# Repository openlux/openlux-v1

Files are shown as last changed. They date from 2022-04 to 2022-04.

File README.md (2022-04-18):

This is the first version of this camera and had a few small design issues, these will be fixed in v2.

# openlux

openlux is an open source design for an astrophotography camera designed around the KAI-11002 CCD sensor.

### Hardware specifications

* 4-layer PCB

* KAI-11002 CCD sensor
  * 4008x2672 resolution
  * 43.3mm diagonal size
  * 9um pixels
  * Interline transfer
  * Electronic shutter

* AD9826 ADC
  * Correlated double sampling
  * 16-bit

* ATmega328P + FT2232H
  * High speed USB 2.0 (480Mb/s)

### Sample photo

* 32x 5min lights (2hrs 40mins total), 16x darks, 16x flats, 16x dark flats
* AT65EDQ + HEQ5
* ST80 & ASI174MM for guiding

M31 sample photo

### PCB render

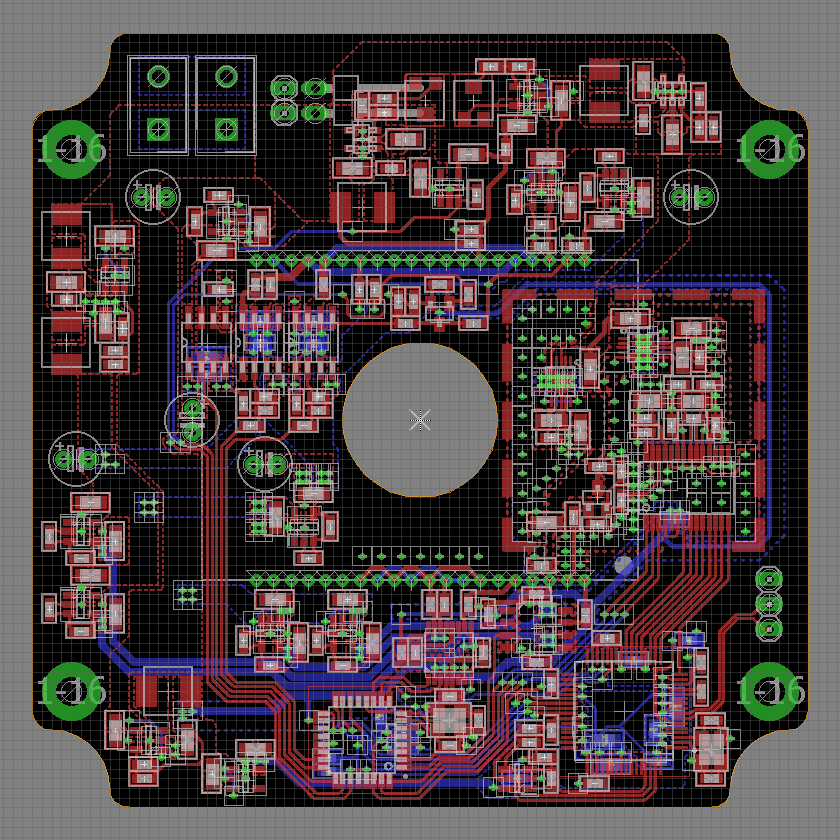
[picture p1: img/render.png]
PCB render


### Photos

PCB photo

Camera photo

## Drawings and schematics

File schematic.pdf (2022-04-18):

A

A

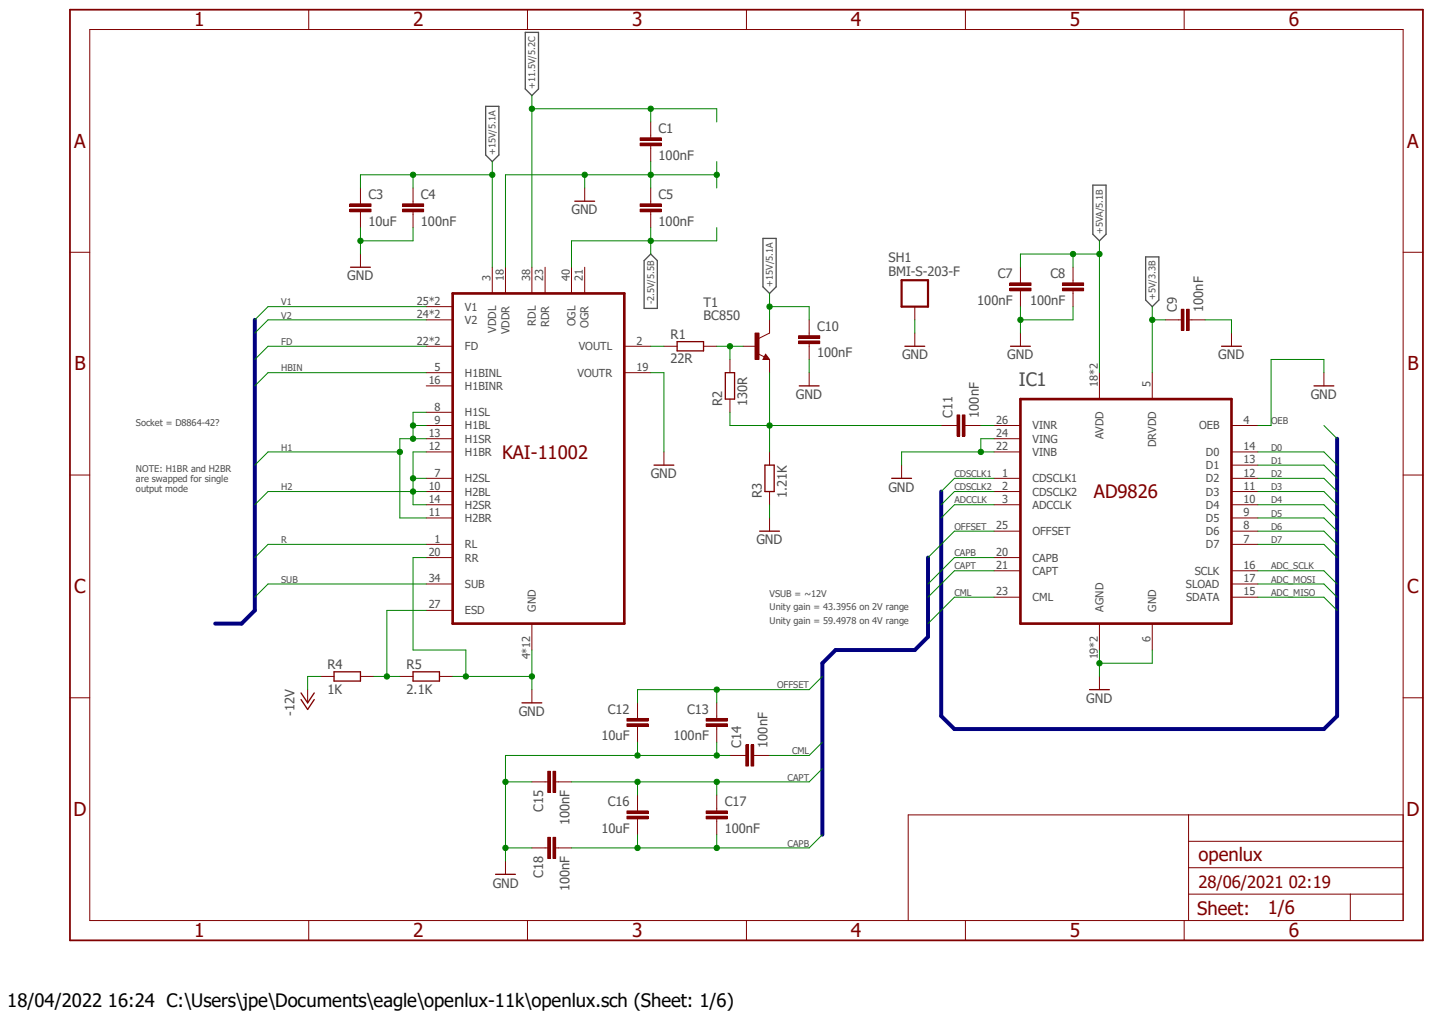
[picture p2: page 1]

NOTE: H1BR and H2BR
are swapped for single
output mode

VSUB = ~12V
Unity gain = 43.3956 on 2V range
Unity gain = 59.4978 on 4V range

18/04/2022 16:24 C:\Users\jpe\Documents\eagle\openlux-11k\openlux.sch (Sheet: 1/6)

A

A

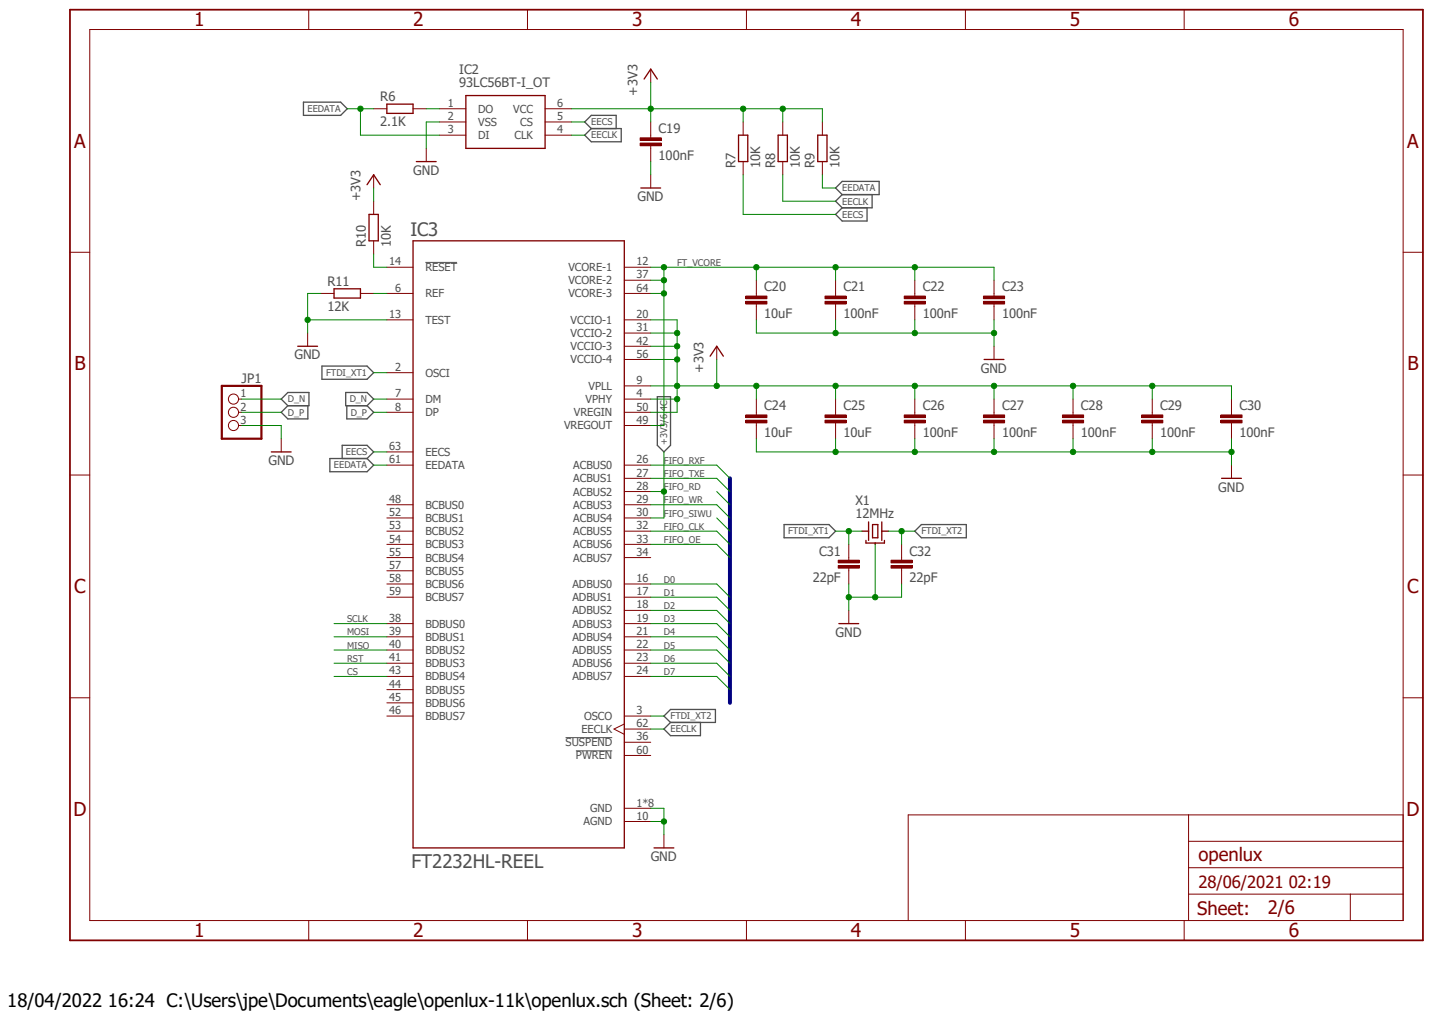
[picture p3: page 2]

18/04/2022 16:24 C:\Users\jpe\Documents\eagle\openlux-11k\openlux.sch (Sheet: 2/6)

## wr IC4

A

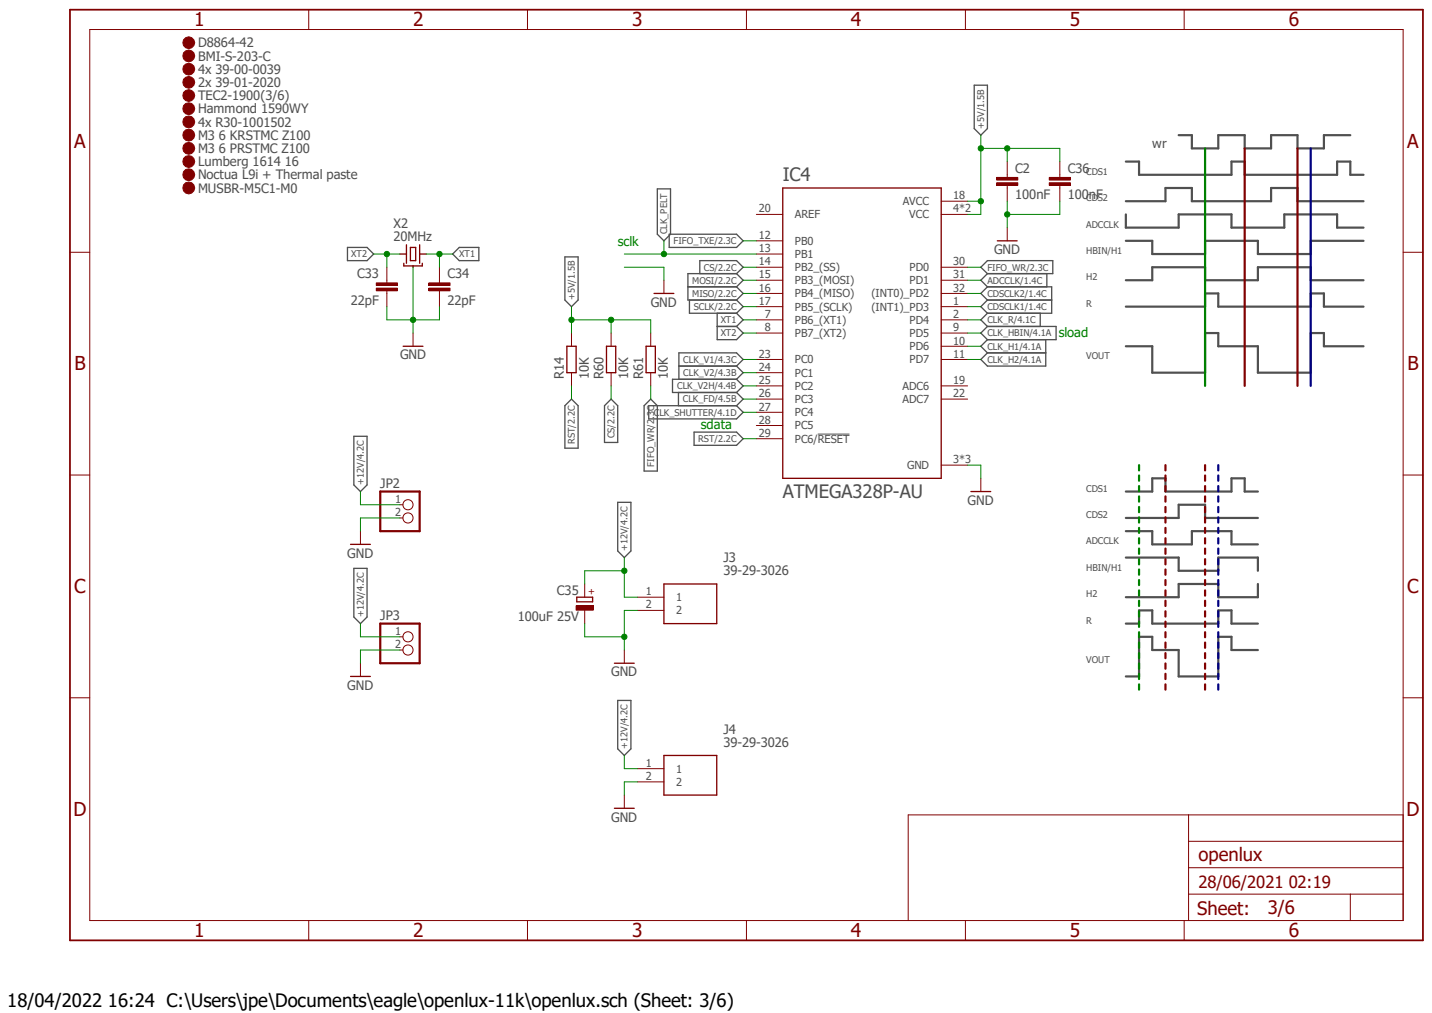
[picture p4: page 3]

18/04/2022 16:24 C:\Users\jpe\Documents\eagle\openlux-11k\openlux.sch (Sheet: 3/6)

A

A

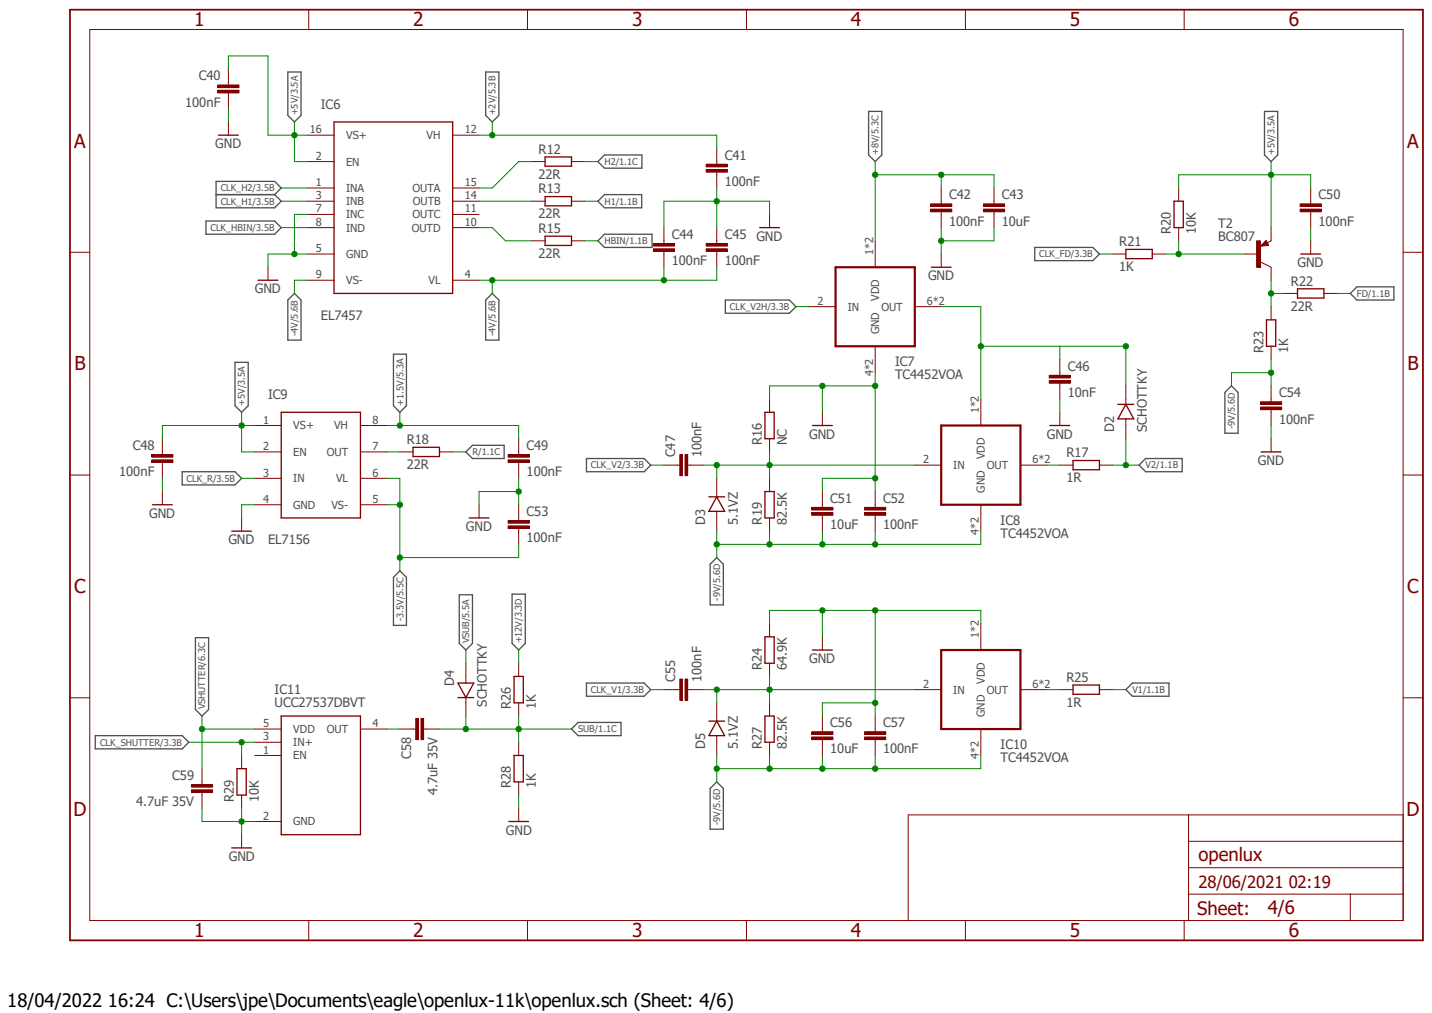
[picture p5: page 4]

18/04/2022 16:24 C:\Users\jpe\Documents\eagle\openlux-11k\openlux.sch (Sheet: 4/6)

OUT | 5 R³¹ R³⁵
C63 | R⁴¹

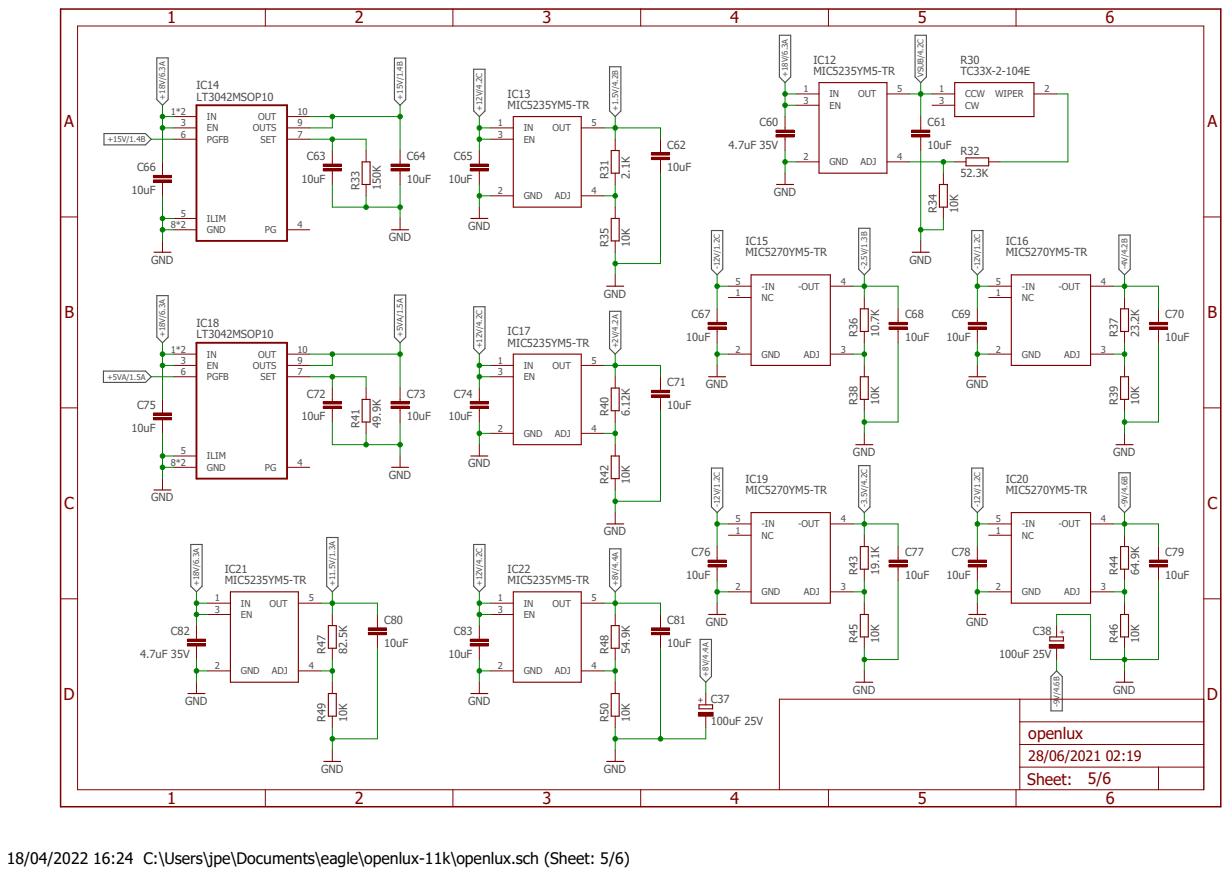
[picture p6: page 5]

18/04/2022 16:24 C:\Users\jpe\Documents\eagle\openlux-11k\openlux.sch (Sheet: 5/6)

A

A

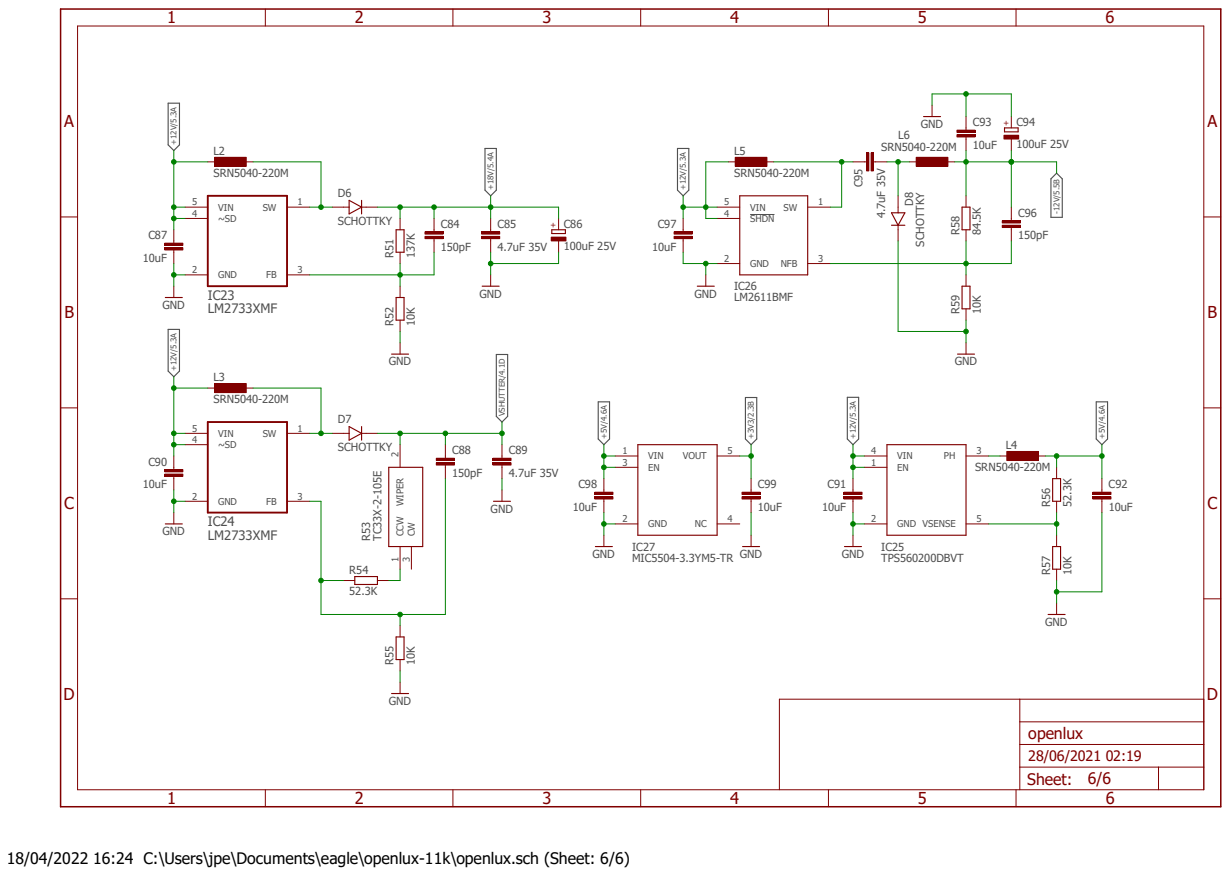
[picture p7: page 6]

18/04/2022 16:24 C:\Users\jpe\Documents\eagle\openlux-11k\openlux.sch (Sheet: 6/6)

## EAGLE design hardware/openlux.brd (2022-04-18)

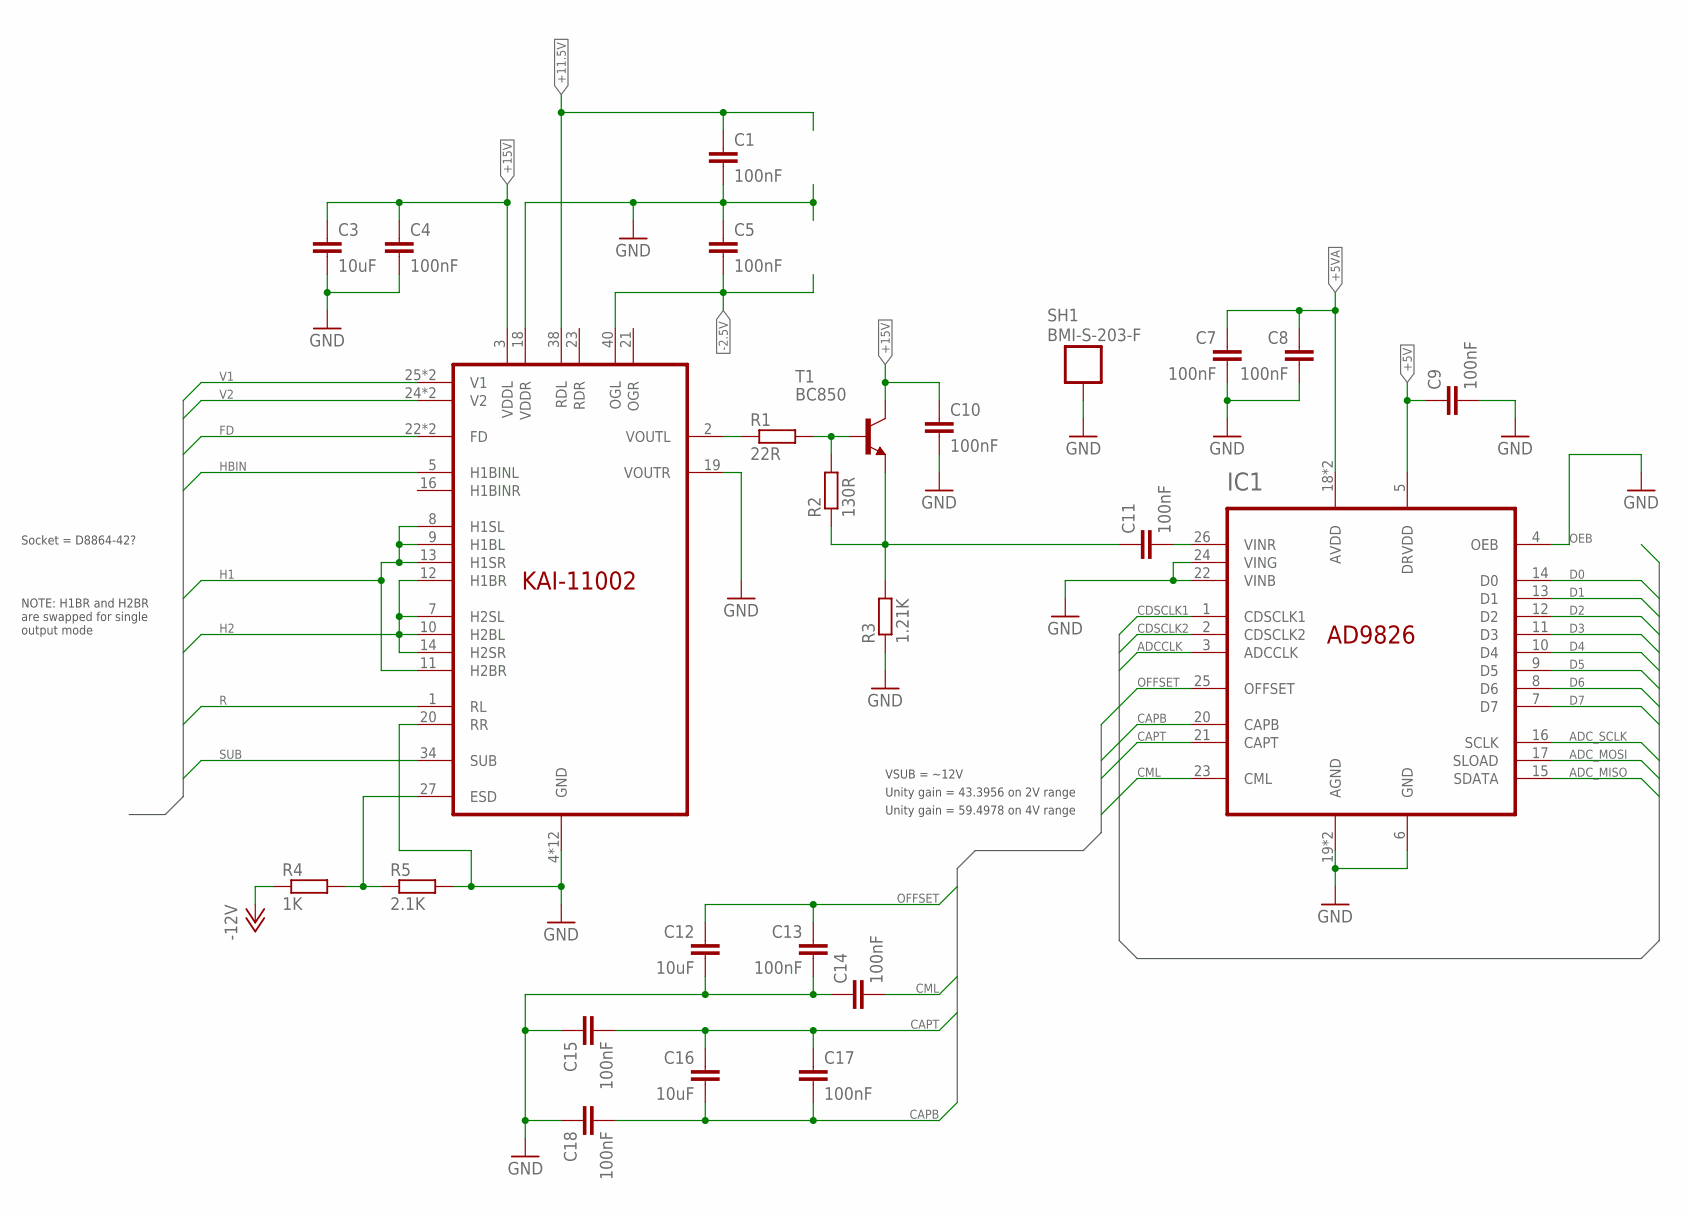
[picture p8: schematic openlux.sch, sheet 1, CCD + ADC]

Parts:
C1, C4, C5, C7, C8, C9, C10, C11, C13, C14, C15, C17, C18: 100nF; 0603
C3, C12, C16: 10uF; 0805
IC1: AD9826; SSOP28
IS1: KAI-11002
R1: 22R; 0603
R2: 130R; 0603
R3: 1.21K; 0603
R4: 1K; 0603
R5: 2.1K; 0603
SH1: BMI-S-203-F
T1: BC850; SOT23

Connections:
+5V: C9.1, IC1.5 (DRVDD); also elsewhere on the board
+5VA: C7.1, C8.1, IC1.18 (AVDD), IC1.28 (AVDD); also elsewhere on the board
+11.5V: C1.1, IS1.38 (RDL); also elsewhere on the board
+15V: C3.1, C4.1, C10.1, IS1.3 (VDDL), T1.3 (C); also elsewhere on the board
-2.5V: C5.2, IS1.40 (OGL); also elsewhere on the board
-12V: R4.1; also elsewhere on the board
ADCCLK: IC1.3 (ADCCLK); also elsewhere on the board
ADC_MISO: IC1.15 (SDATA)
ADC_MOSI: IC1.17 (SLOAD)
ADC_SCLK: IC1.16 (SCLK)
CAPB: C16.2, C17.2, C18.2, IC1.20 (CAPB)
CAPT: C15.2, C16.1, C17.1, IC1.21 (CAPT)
CDSCLK1: IC1.1 (CDSCLK1); also elsewhere on the board
CDSCLK2: IC1.2 (CDSCLK2); also elsewhere on the board
CML: C14.2, IC1.23 (CML)
D0: IC1.14 (D0); also elsewhere on the board
D1: IC1.13 (D1); also elsewhere on the board
D2: IC1.12 (D2); also elsewhere on the board
D3: IC1.11 (D3); also elsewhere on the board
D4: IC1.10 (D4); also elsewhere on the board
D5: IC1.9 (D5); also elsewhere on the board
D6: IC1.8 (D6); also elsewhere on the board
D7: IC1.7 (D7); also elsewhere on the board
FD: IS1.22 (FD), IS1.39 (FD); also elsewhere on the board
GND: C1.2, C3.2, C4.2, C5.1, C7.2, C8.2, C9.2, C10.2, C12.2, C13.2, C14.1, C15.1, C18.1, IC1.4 (OEB), IC1.6 (GND), IC1.19 (AGND), IC1.22 (VINB), IC1.24 (VING), IC1.27 (AGND), IS1.4 (GND), IS1.6 (GND), IS1.15 (GND), IS1.17 (GND), IS1.18 (VDDR), IS1.19 (VOUTR), IS1.20 (RR), IS1.26 (GND), IS1.28 (GND), IS1.29 (GND), IS1.30 (GND), IS1.31 (GND), IS1.32 (GND), IS1.33 (GND), IS1.35 (GND), R3.1, R5.2, SH1.P$1, SH1.P$2, SH1.P$3, SH1.P$4, SH1.P$5, SH1.P$6, SH1.P$7, SH1.P$8, SH1.P$9, SH1.P$10, SH1.P$11, SH1.P$12, SH1.P$13, SH1.P$14, SH1.P$15, SH1.P$19, SH1.P$20; also elsewhere on the board
H1: IS1.8 (H1SL), IS1.9 (H1BL), IS1.11 (H2BR), IS1.13 (H1SR); also elsewhere on the board
H2: IS1.7 (H2SL), IS1.10 (H2BL), IS1.12 (H1BR), IS1.14 (H2SR); also elsewhere on the board
HBIN: IS1.5 (H1BINL); also elsewhere on the board
unnamed: R1.2, R2.2, T1.1 (B)
unnamed: C11.2, IC1.26 (VINR)
unnamed: IS1.2 (VOUTL), R1.1
OFFSET: C12.1, C13.1, IC1.25 (OFFSET)
R: IS1.1 (RL); also elsewhere on the board
SUB: IS1.34 (SUB); also elsewhere on the board
V1: IS1.25 (V1), IS1.37 (V1); also elsewhere on the board
V2: IS1.24 (V2), IS1.36 (V2); also elsewhere on the board
VESD: IS1.27 (ESD), R4.2, R5.1
VOUT: C11.1, R2.1, R3.2, T1.2 (E)

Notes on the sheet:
NOTE: H1BR and H2BR are swapped for single output mode
Unity gain = 43.3956 on 2V range
Unity gain = 59.4978 on 4V range
Socket = D8864-42?
VSUB = ~12V

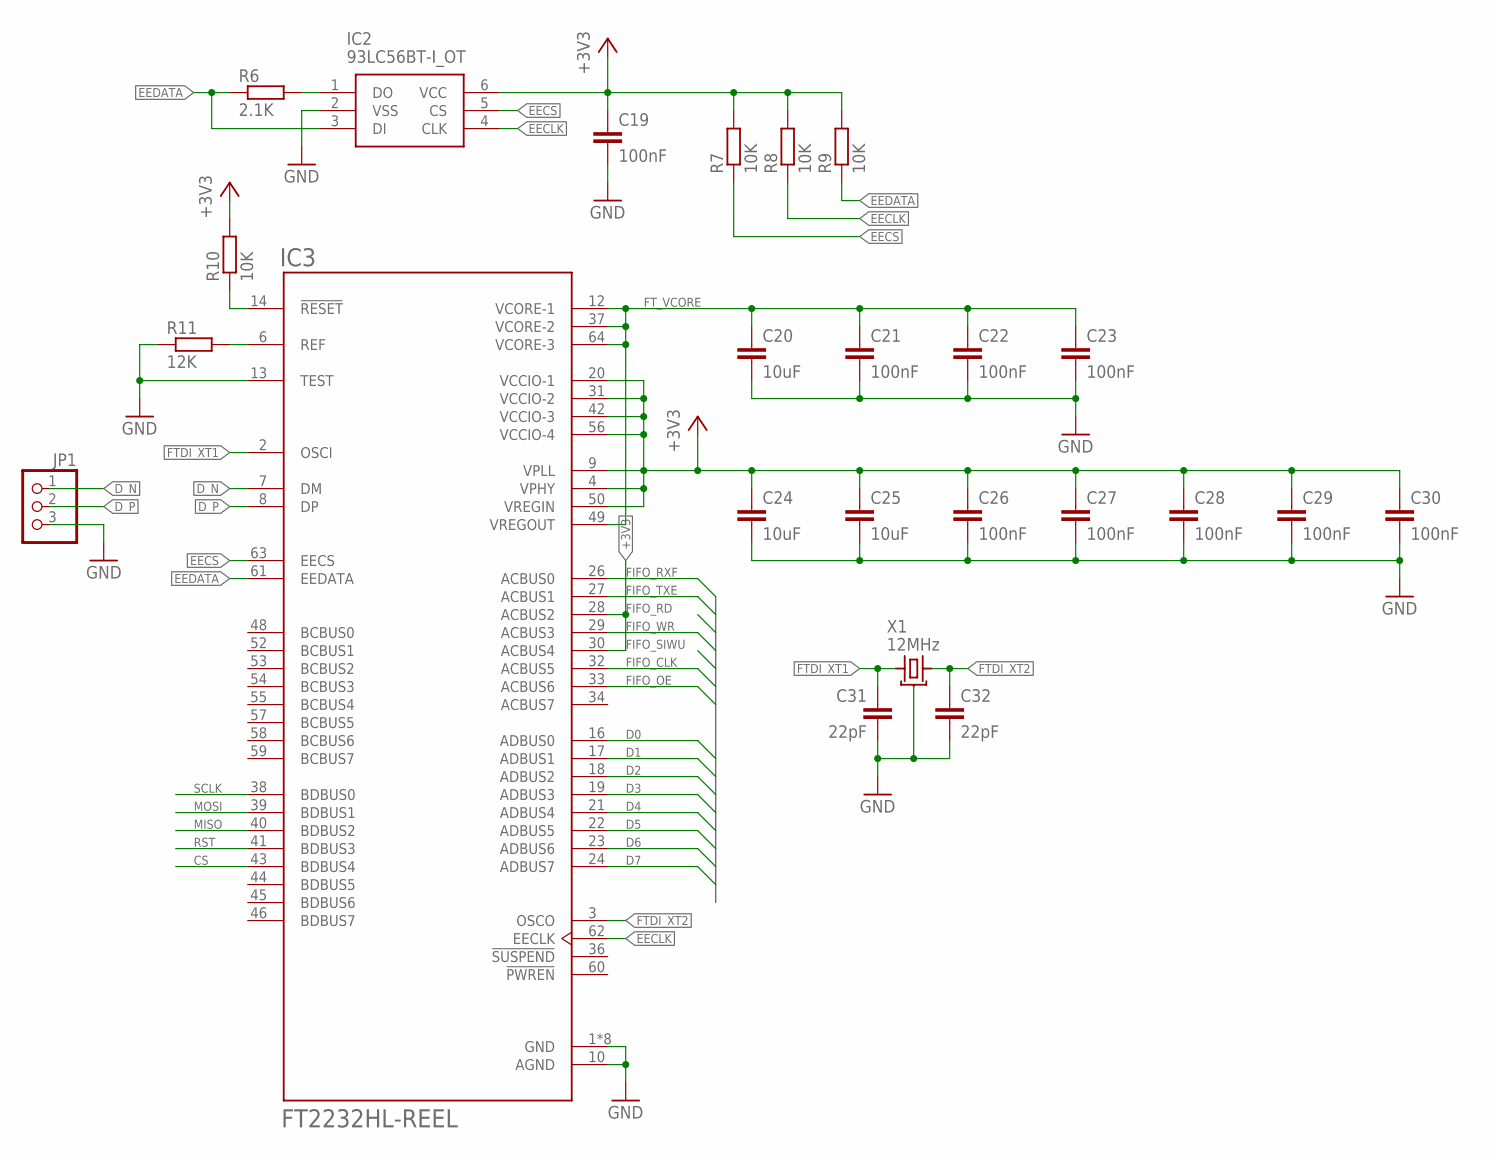
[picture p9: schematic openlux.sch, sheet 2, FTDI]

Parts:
C19, C21, C22, C23, C26, C27, C28, C29, C30: 100nF; 0603
C20, C24, C25: 10uF; 0805
C31, C32: 22pF; 0603
IC2: 93LC56BT-I_OT; SOT95P270X145-6N
IC3: FT2232HL-REEL; QFP50P1200X1200X160-64N
JP1: PINHD-1X3; 1X03
R6: 2.1K; 0603
R7, R8, R9, R10: 10K; 0603
R11: 12K; 0603
X1: 12MHz; 3.2X2.5_4

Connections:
+3V3: C19.1, C24.1, C25.1, C26.1, C27.1, C28.1, C29.1, C30.1, IC2.6 (VCC), IC3.4 (VPHY), IC3.9 (VPLL), IC3.20 (VCCIO-1), IC3.28 (ACBUS2), IC3.30 (ACBUS4), IC3.31 (VCCIO-2), IC3.42 (VCCIO-3), IC3.50 (VREGIN), IC3.56 (VCCIO-4), R7.2, R8.2, R9.2, R10.2; also elsewhere on the board
CS: IC3.43 (BDBUS4); also elsewhere on the board
D0: IC3.16 (ADBUS0); also elsewhere on the board
D1: IC3.17 (ADBUS1); also elsewhere on the board
D2: IC3.18 (ADBUS2); also elsewhere on the board
D3: IC3.19 (ADBUS3); also elsewhere on the board
D4: IC3.21 (ADBUS4); also elsewhere on the board
D5: IC3.22 (ADBUS5); also elsewhere on the board
D6: IC3.23 (ADBUS6); also elsewhere on the board
D7: IC3.24 (ADBUS7); also elsewhere on the board
D_N: IC3.7 (DM), JP1.1
D_P: IC3.8 (DP), JP1.2
EECLK: IC2.4 (CLK), IC3.62 (EECLK), R8.1
EECS: IC2.5 (CS), IC3.63 (EECS), R7.1
EEDATA: IC2.3 (DI), IC3.61 (EEDATA), R6.1, R9.1
FIFO_CLK: IC3.32 (ACBUS5)
FIFO_OE: IC3.33 (ACBUS6)
FIFO_RXF: IC3.26 (ACBUS0)
FIFO_TXE: IC3.27 (ACBUS1); also elsewhere on the board
FIFO_WR: IC3.29 (ACBUS3); also elsewhere on the board
FTDI_XT1: C31.1, IC3.2 (OSCI), X1.P$1 (XT1)
FTDI_XT2: C32.1, IC3.3 (OSCO), X1.P$3 (XT2)
FT_VCORE: C20.1, C21.1, C22.1, C23.1, IC3.12 (VCORE-1), IC3.37 (VCORE-2), IC3.49 (VREGOUT), IC3.64 (VCORE-3)
GND: C19.2, C20.2, C21.2, C22.2, C23.2, C24.2, C25.2, C26.2, C27.2, C28.2, C29.2, C30.2, C31.2, C32.2, IC2.2 (VSS), IC3.1 (GND), IC3.5 (GND), IC3.10 (AGND), IC3.11 (GND), IC3.13 (TEST), IC3.15 (GND), IC3.25 (GND), IC3.35 (GND), IC3.47 (GND), IC3.51 (GND), JP1.3, R11.1, X1.P$2 (GND), X1.P$4 (GND); also elsewhere on the board
MISO: IC3.40 (BDBUS2); also elsewhere on the board
MOSI: IC3.39 (BDBUS1); also elsewhere on the board
unnamed: IC3.6 (REF), R11.2
unnamed: IC2.1 (DO), R6.2
unnamed: IC3.14 (!RESET), R10.1
RST: IC3.41 (BDBUS3); also elsewhere on the board
SCLK: IC3.38 (BDBUS0); also elsewhere on the board

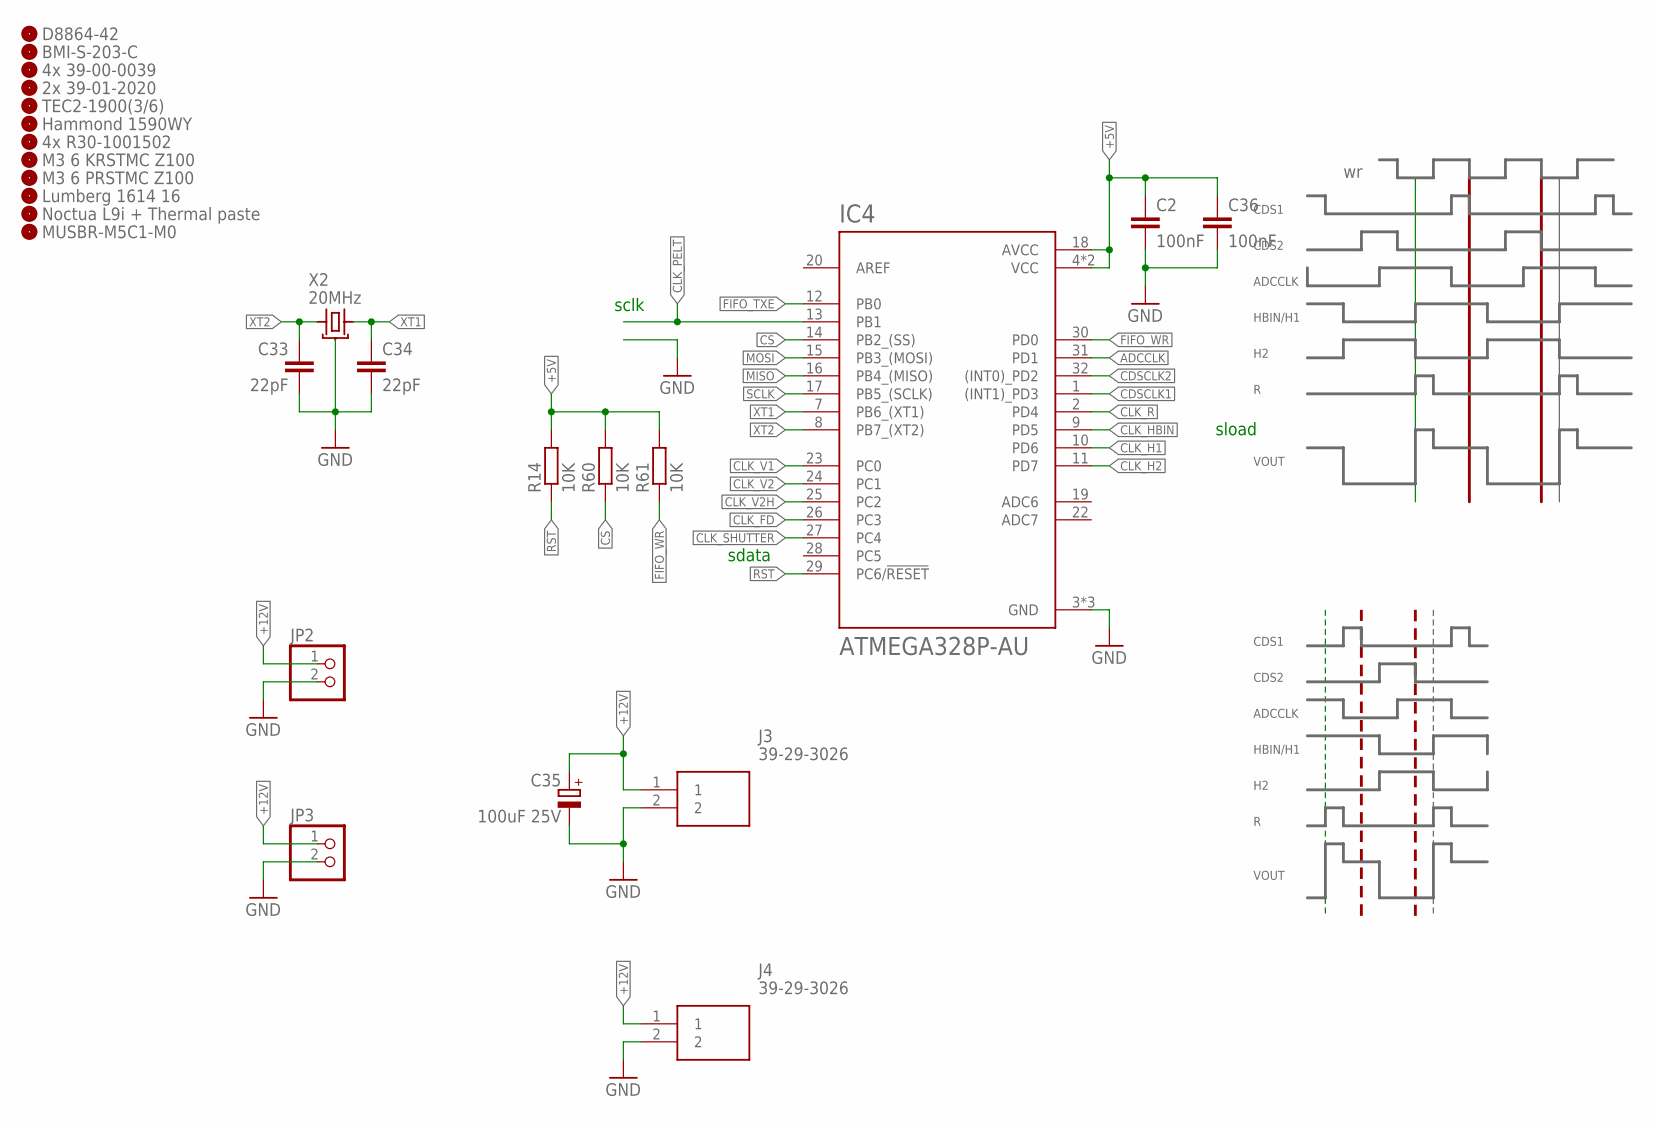
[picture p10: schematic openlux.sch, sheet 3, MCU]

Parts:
C2, C36: 100nF; 0603
C33, C34: 22pF; 0603
C35: 100uF 25V; E2,5-6
EXTRA1: 4x R30-1001502; EMPTY
EXTRA2: Hammond 1590WY; EMPTY
EXTRA3: M3 6 KRSTMC Z100; EMPTY
EXTRA4: M3 6 PRSTMC Z100; EMPTY
EXTRA5: TEC2-1900(3/6); EMPTY
EXTRA6: 2x 39-01-2020; EMPTY
EXTRA7: 4x 39-00-0039; EMPTY
EXTRA8: Lumberg 1614 16; EMPTY
EXTRA9: Noctua L9i + Thermal paste; EMPTY
EXTRA10: MUSBR-M5C1-M0; EMPTY
EXTRA11: BMI-S-203-C; EMPTY
EXTRA12: D8864-42; EMPTY
IC4: ATMEGA328P-AU; QFP80P900X900X120-32N
J3, J4: 39-29-3026; SHDR2W125P0X550_1X2_960X540X13
JP2: PINHD-1X2; 1X02
JP3: PINHD-1X2/90; 1X02/90
R14, R60, R61: 10K; 0603
X2: 20MHz; 3.2X2.5_4

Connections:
+5V: C2.1, C36.1, IC4.4 (VCC), IC4.6 (VCC), IC4.18 (AVCC), R14.2, R60.2, R61.2; also elsewhere on the board
+12V: C35.+, J3.1, J4.1, JP2.1, JP3.1; also elsewhere on the board
ADCCLK: IC4.31 (PD1); also elsewhere on the board
CDSCLK1: IC4.1 ((INT1)_PD3); also elsewhere on the board
CDSCLK2: IC4.32 ((INT0)_PD2); also elsewhere on the board
CLK_FD: IC4.26 (PC3); also elsewhere on the board
CLK_H1: IC4.10 (PD6); also elsewhere on the board
CLK_H2: IC4.11 (PD7); also elsewhere on the board
CLK_HBIN: IC4.9 (PD5); also elsewhere on the board
CLK_PELT: IC4.13 (PB1)
CLK_R: IC4.2 (PD4); also elsewhere on the board
CLK_SHUTTER: IC4.27 (PC4); also elsewhere on the board
CLK_V1: IC4.23 (PC0); also elsewhere on the board
CLK_V2: IC4.24 (PC1); also elsewhere on the board
CLK_V2H: IC4.25 (PC2); also elsewhere on the board
CS: IC4.14 (PB2_(SS)), R60.1; also elsewhere on the board
FIFO_TXE: IC4.12 (PB0); also elsewhere on the board
FIFO_WR: IC4.30 (PD0), R61.1; also elsewhere on the board
GND: C2.2, C33.2, C34.2, C35.-, C36.2, IC4.3 (GND), IC4.5 (GND), IC4.21 (GND), J3.2, J4.2, JP2.2, JP3.2, X2.P$2 (GND), X2.P$4 (GND); also elsewhere on the board
MISO: IC4.16 (PB4_(MISO)); also elsewhere on the board
MOSI: IC4.15 (PB3_(MOSI)); also elsewhere on the board
RST: IC4.29 (PC6/!RESET), R14.1; also elsewhere on the board
SCLK: IC4.17 (PB5_(SCLK)); also elsewhere on the board
XT1: C34.1, IC4.7 (PB6_(XT1)), X2.P$3 (XT2)
XT2: C33.1, IC4.8 (PB7_(XT2)), X2.P$1 (XT1)

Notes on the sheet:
HBIN/H1
ADCCLK
CDS1
CDS2
VOUT
sload
sclk
sdata

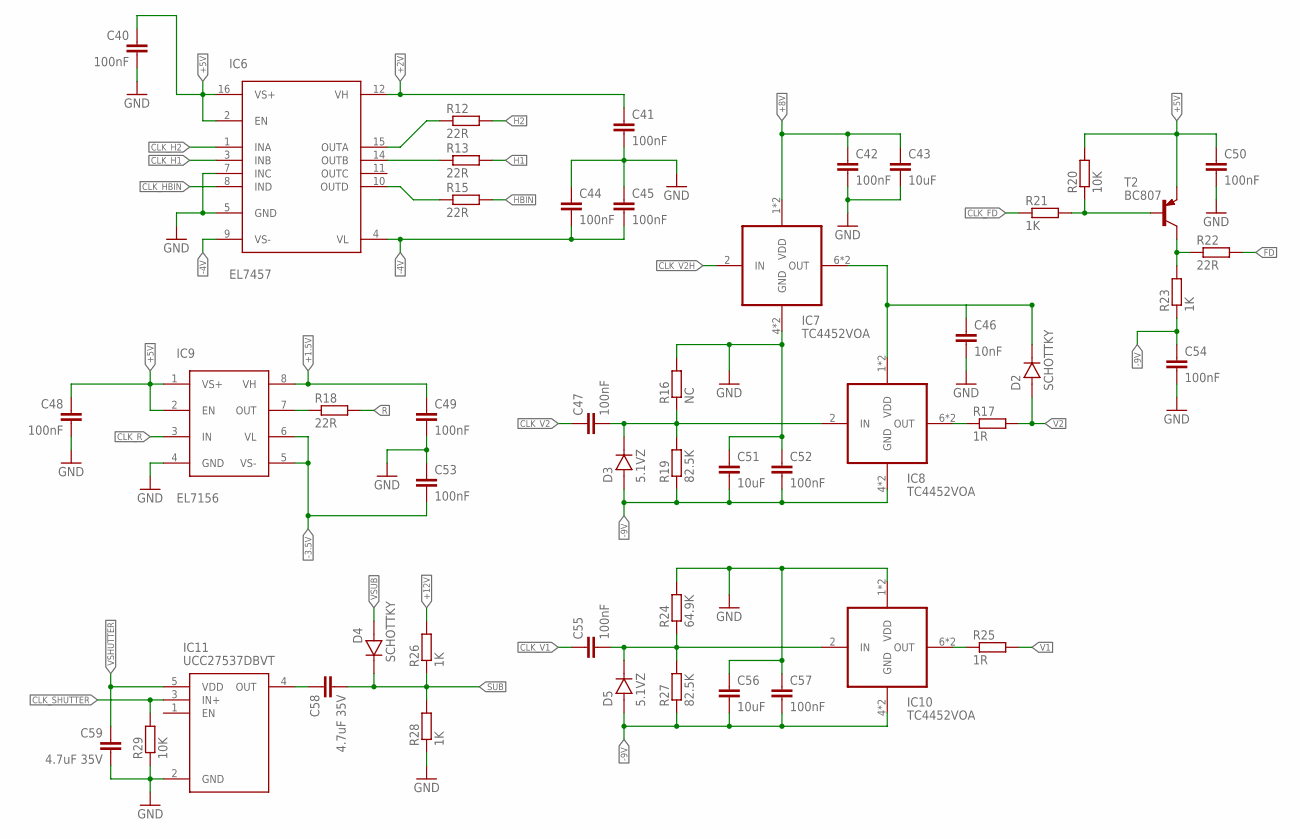
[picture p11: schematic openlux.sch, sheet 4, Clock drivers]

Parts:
C40, C41, C42, C44, C45, C47, C48, C49, C50, C52, C53, C54, C55, C57: 100nF; 0603
C43, C51, C56: 10uF; 0805
C46: 10nF; 0603
C58, C59: 4.7uF 35V; 0805
D2, D4: SCHOTTKY; SOD523
D3, D5: 5.1VZ; SOD523
IC6: EL7457; QSOP16
IC7, IC8, IC10: TC4452VOA; SOIC8
IC9: EL7156; SOIC8
IC11: UCC27537DBVT; SOT95P280X145-5N
R12, R13, R15, R18, R22: 22R; 0603
R16: NC; 0603
R17, R25: 1R; 0603
R19, R27: 82.5K; 0603
R20, R29: 10K; 0603
R21, R23, R26, R28: 1K; 0603
R24: 64.9K; 0603
T2: BC807; SOT23-BEC

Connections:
+1.5V: C49.1, IC9.8 (VH); also elsewhere on the board
+2V: C41.1, IC6.12 (VH); also elsewhere on the board
+5V: C40.1, C48.1, C50.1, IC6.2 (EN), IC6.16 (VS+), IC9.1 (VS+), IC9.2 (EN), R20.2, T2.E; also elsewhere on the board
+8V: C42.1, C43.1, IC7.1 (VDD), IC7.8 (VDD); also elsewhere on the board
+12V: R26.2; also elsewhere on the board
-3.5V: C53.2, IC9.5 (VS-), IC9.6 (VL); also elsewhere on the board
-4V: C44.2, C45.2, IC6.4 (VL), IC6.9 (VS-); also elsewhere on the board
-9V: C51.2, C52.2, C54.1, C56.2, C57.2, D3.1, D5.1, IC8.4 (GND), IC8.5 (GND), IC10.4 (GND), IC10.5 (GND), R19.1, R23.1, R27.1; also elsewhere on the board
CLK_FD: R21.1; also elsewhere on the board
CLK_H1: IC6.3 (INB); also elsewhere on the board
CLK_H2: IC6.1 (INA); also elsewhere on the board
CLK_HBIN: IC6.8 (IND); also elsewhere on the board
CLK_R: IC9.3 (IN); also elsewhere on the board
CLK_SHUTTER: IC11.3 (IN+), R29.2; also elsewhere on the board
CLK_V1: C55.1; also elsewhere on the board
CLK_V2: C47.1; also elsewhere on the board
CLK_V2H: IC7.2 (IN); also elsewhere on the board
FD: R22.2; also elsewhere on the board
GND: C40.2, C41.2, C42.2, C43.2, C44.1, C45.1, C46.2, C48.2, C49.2, C50.2, C51.1, C52.1, C53.1, C54.2, C56.1, C57.1, C59.2, IC6.5 (GND), IC6.7 (INC), IC7.4 (GND), IC7.5 (GND), IC9.4 (GND), IC10.1 (VDD), IC10.8 (VDD), IC11.2 (GND), R16.2, R24.2, R28.1, R29.1; also elsewhere on the board
H1: R13.2; also elsewhere on the board
H2: R12.2; also elsewhere on the board
HBIN: R15.2; also elsewhere on the board
unnamed: IC9.7 (OUT), R18.1
unnamed: C47.2, D3.2, IC8.2 (IN), R16.1, R19.2
unnamed: C58.1, IC11.4 (OUT)
unnamed: IC6.14 (OUTB), R13.1
unnamed: IC6.15 (OUTA), R12.1
unnamed: IC6.10 (OUTD), R15.1
unnamed: C55.2, D5.2, IC10.2 (IN), R24.1, R27.2
unnamed: R22.1, R23.2, T2.C
unnamed: R20.1, R21.2, T2.B
R: R18.2; also elsewhere on the board
SUB: C58.2, D4.2, R26.1, R28.2; also elsewhere on the board
V1: R25.2; also elsewhere on the board
V1P: IC10.6 (OUT), IC10.7 (OUT), R25.1
V2: D2.1, R17.2; also elsewhere on the board
V2H: C46.1, D2.2, IC7.6 (OUT), IC7.7 (OUT), IC8.1 (VDD), IC8.8 (VDD)
V2P: IC8.6 (OUT), IC8.7 (OUT), R17.1
VSHUTTER: C59.1, IC11.5 (VDD); also elsewhere on the board
VSUB: D4.1; also elsewhere on the board

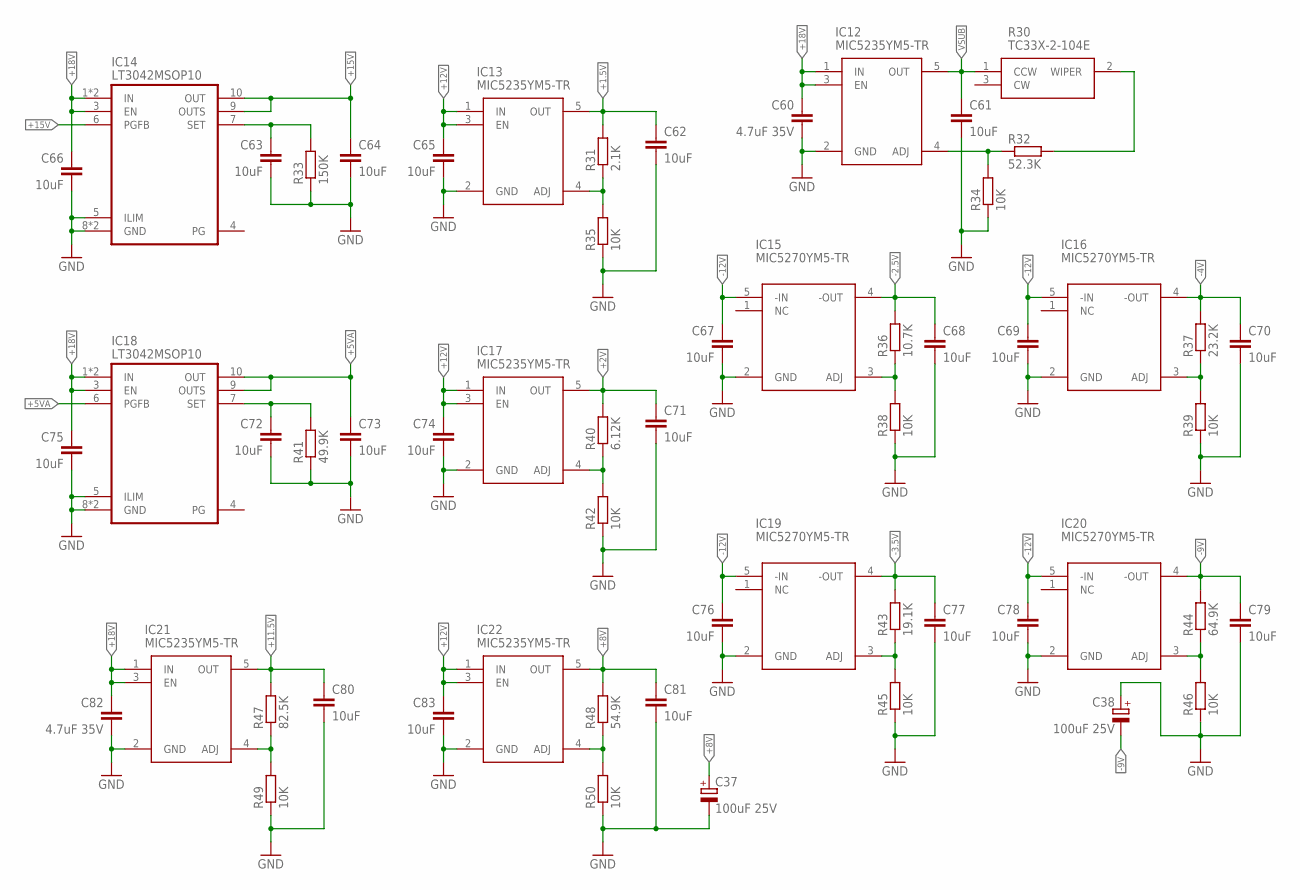
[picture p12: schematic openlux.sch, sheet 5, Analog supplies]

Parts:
C37, C38: 100uF 25V; E2,5-6
C60, C82: 4.7uF 35V; 0805
C61, C62, C63, C64, C65, C66, C67, C68, C69, C70, C71, C72, C73, C74, C75, C76, C77, C78, C79, C80, C81, C83: 10uF; 0805
IC12, IC13, IC17, IC21, IC22: MIC5235YM5-TR; SOT95P280X145-5N
IC14, IC18: LT3042MSOP10; MSOP10
IC15, IC16, IC19, IC20: MIC5270YM5-TR; SOT95P280X145-5N
R30: TC33X-2-104E; TC33X2
R31: 2.1K; 0603
R32: 52.3K; 0603
R33: 150K; 0603
R34, R35, R38, R39, R42, R45, R46, R49, R50: 10K; 0603
R36: 10.7K; 0603
R37: 23.2K; 0603
R40: 6.12K; 0603
R41: 49.9K; 0603
R43: 19.1K; 0603
R44: 64.9K; 0603
R47: 82.5K; 0603
R48: 54.9K; 0603

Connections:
+1.5V: C62.1, IC13.5 (OUT), R31.2; also elsewhere on the board
+2V: C71.1, IC17.5 (OUT), R40.2; also elsewhere on the board
+5VA: C73.1, IC18.6 (PGFB), IC18.9 (OUTS), IC18.10 (OUT); also elsewhere on the board
+8V: C37.+, C81.1, IC22.5 (OUT), R48.2; also elsewhere on the board
+11.5V: C80.1, IC21.5 (OUT), R47.2; also elsewhere on the board
+12V: C65.1, C74.1, C83.1, IC13.1 (IN), IC13.3 (EN), IC17.1 (IN), IC17.3 (EN), IC22.1 (IN), IC22.3 (EN); also elsewhere on the board
+15V: C64.1, IC14.6 (PGFB), IC14.9 (OUTS), IC14.10 (OUT); also elsewhere on the board
+18V: C60.1, C66.1, C75.1, C82.1, IC12.1 (IN), IC12.3 (EN), IC14.1 (IN), IC14.2 (IN), IC14.3 (EN), IC18.1 (IN), IC18.2 (IN), IC18.3 (EN), IC21.1 (IN), IC21.3 (EN); also elsewhere on the board
-2.5V: C68.1, IC15.4 (-OUT), R36.2; also elsewhere on the board
-3.5V: C77.1, IC19.4 (-OUT), R43.2; also elsewhere on the board
-4V: C70.1, IC16.4 (-OUT), R37.2; also elsewhere on the board
-9V: C38.-, C79.1, IC20.4 (-OUT), R44.2; also elsewhere on the board
-12V: C67.1, C69.1, C76.1, C78.1, IC15.5 (-IN), IC16.5 (-IN), IC19.5 (-IN), IC20.5 (-IN); also elsewhere on the board
GND: C37.-, C38.+, C60.2, C61.2, C62.2, C63.2, C64.2, C65.2, C66.2, C67.2, C68.2, C69.2, C70.2, C71.2, C72.2, C73.2, C74.2, C75.2, C76.2, C77.2, C78.2, C79.2, C80.2, C81.2, C82.2, C83.2, IC12.2 (GND), IC13.2 (GND), IC14.5 (ILIM), IC14.8 (GND), IC14.EP (GND), IC15.2 (GND), IC16.2 (GND), IC17.2 (GND), IC18.5 (ILIM), IC18.8 (GND), IC18.EP (GND), IC19.2 (GND), IC20.2 (GND), IC21.2 (GND), IC22.2 (GND), R33.1, R34.1, R35.1, R38.1, R39.1, R41.1, R42.1, R45.1, R46.1, R49.1, R50.1; also elsewhere on the board
unnamed: IC20.3 (ADJ), R44.1, R46.2
unnamed: IC22.4 (ADJ), R48.1, R50.2
unnamed: IC13.4 (ADJ), R31.1, R35.2
unnamed: IC19.3 (ADJ), R43.1, R45.2
unnamed: IC12.4 (ADJ), R32.1, R34.2
unnamed: IC16.3 (ADJ), R37.1, R39.2
unnamed: IC15.3 (ADJ), R36.1, R38.2
unnamed: IC17.4 (ADJ), R40.1, R42.2
unnamed: R30.2 (WIPER), R32.2
unnamed: C63.1, IC14.7 (SET), R33.2
unnamed: IC21.4 (ADJ), R47.1, R49.2
unnamed: C72.1, IC18.7 (SET), R41.2
VSUB: C61.1, IC12.5 (OUT), R30.1 (CCW); also elsewhere on the board

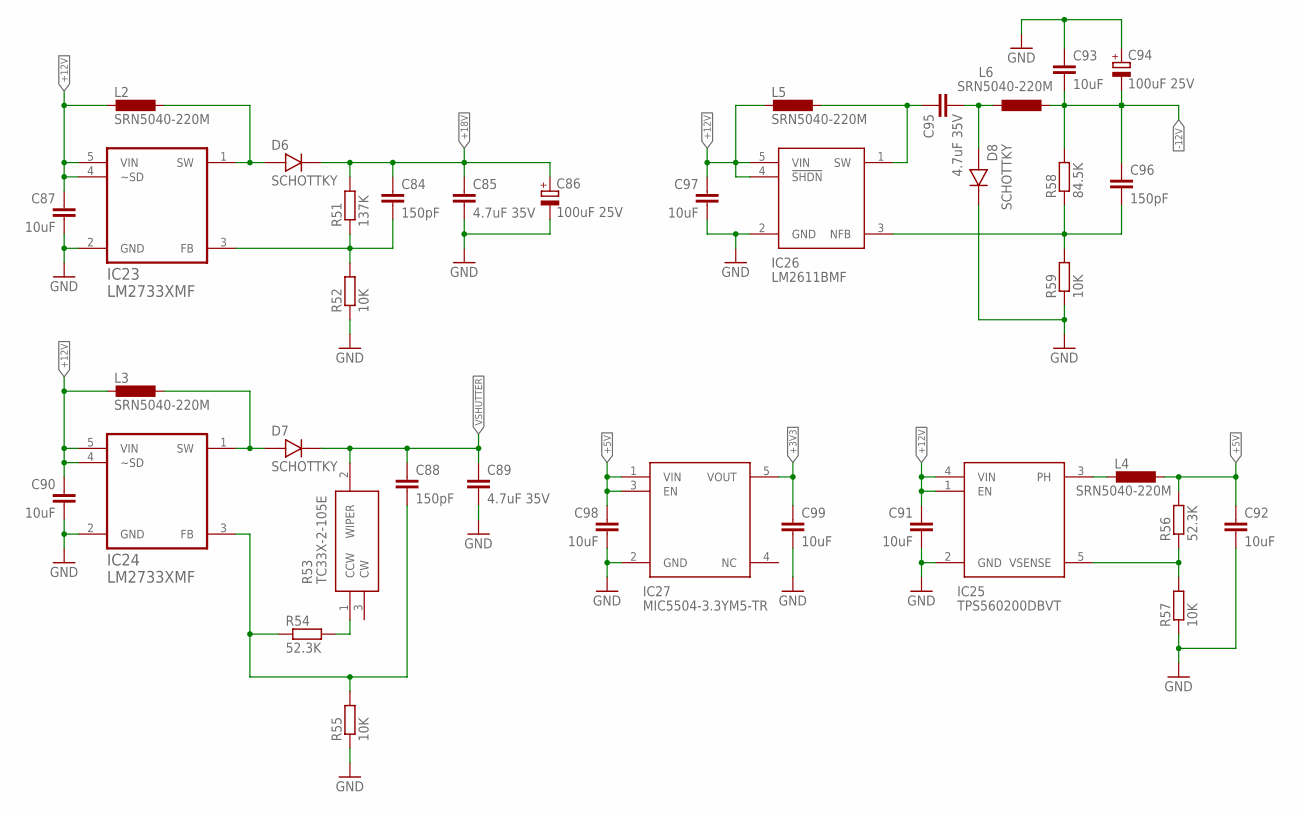
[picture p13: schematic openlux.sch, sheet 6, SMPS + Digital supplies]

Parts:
C84, C88, C96: 150pF; 0603
C85, C89, C95: 4.7uF 35V; 0805
C86, C94: 100uF 25V; E2,5-6
C87, C90, C91, C92, C93, C97, C98, C99: 10uF; 0805
D6, D7, D8: SCHOTTKY; SOD523
IC23, IC24: LM2733XMF; SOT95P284X119-5N
IC25: TPS560200DBVT; SOT95P280X145-5N
IC26: LM2611BMF; SOT95P280X145-5N
IC27: MIC5504-3.3YM5-TR; SOT95P280X130-5N
L2, L3, L4, L5, L6: SRN5040-220M; 5X5_2
R51: 137K; 0603
R52, R55, R57, R59: 10K; 0603
R53: TC33X-2-105E; TC33X2
R54, R56: 52.3K; 0603
R58: 84.5K; 0603

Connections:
18VSH: D6.1, IC23.1 (SW), L2.P$1 (1)
+3V3: C99.1, IC27.5 (VOUT); also elsewhere on the board
+5V: C92.1, C98.1, IC27.1 (VIN), IC27.3 (EN), L4.P$1 (1), R56.2; also elsewhere on the board
+12V: C87.1, C90.1, C91.1, C97.1, IC23.4 (~SD), IC23.5 (VIN), IC24.4 (~SD), IC24.5 (VIN), IC25.1 (EN), IC25.4 (VIN), IC26.4 (!SHDN), IC26.5 (VIN), L2.P$2 (2), L3.P$2 (2), L5.P$2 (2); also elsewhere on the board
+18V: C84.1, C85.1, C86.+, D6.2, R51.2; also elsewhere on the board
-12V: C93.2, C94.-, C96.1, L6.P$1 (1), R58.2; also elsewhere on the board
-12V_SW: C95.1, IC26.1 (SW), L5.P$1 (1)
-12V_SWB: C95.2, D8.1, L6.P$2 (2)
GND: C85.2, C86.-, C87.2, C89.2, C90.2, C91.2, C92.2, C93.1, C94.+, C97.2, C98.2, C99.2, D8.2, IC23.2 (GND), IC24.2 (GND), IC25.2 (GND), IC26.2 (GND), IC27.2 (GND), R52.1, R55.1, R57.1, R59.1; also elsewhere on the board
unnamed: C96.2, IC26.3 (NFB), R58.1, R59.2
unnamed: R53.1 (CCW), R54.2
unnamed: C88.2, IC24.3 (FB), R54.1, R55.2
unnamed: IC25.3 (PH), L4.P$2 (2)
unnamed: IC25.5 (VSENSE), R56.1, R57.2
unnamed: C84.2, IC23.3 (FB), R51.1, R52.2
VSHTVSH: D7.1, IC24.1 (SW), L3.P$1 (1)
VSHUTTER: C88.1, C89.1, D7.2, R53.2 (WIPER); also elsewhere on the board

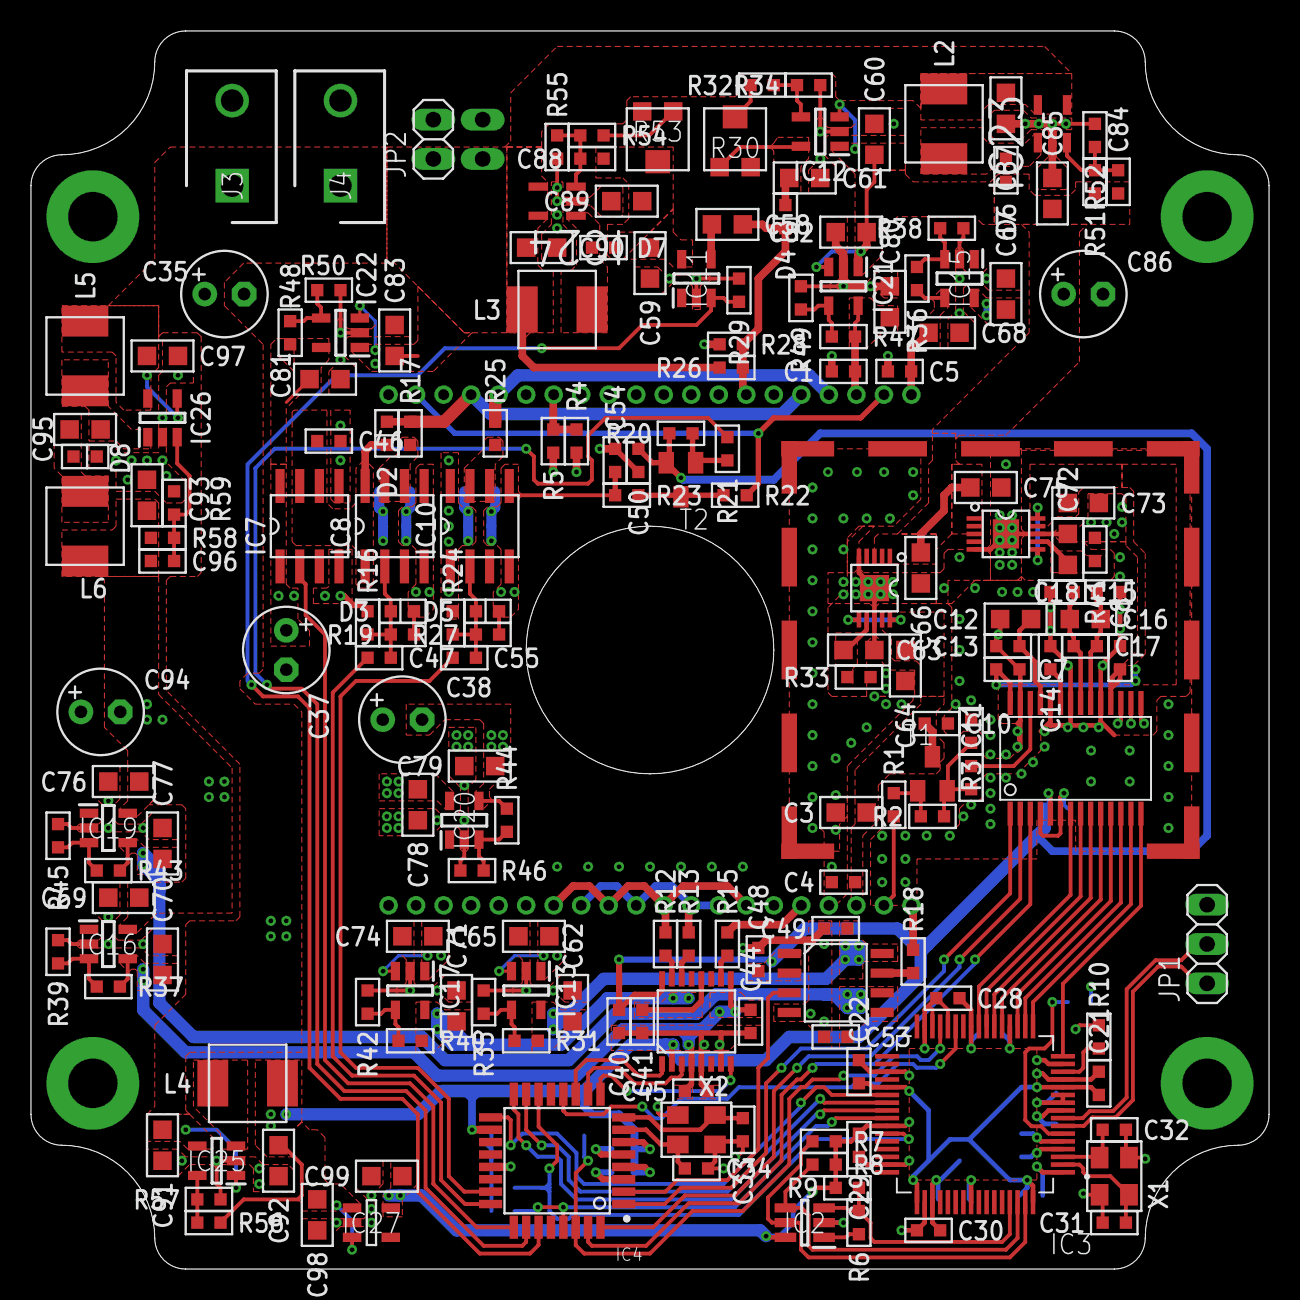
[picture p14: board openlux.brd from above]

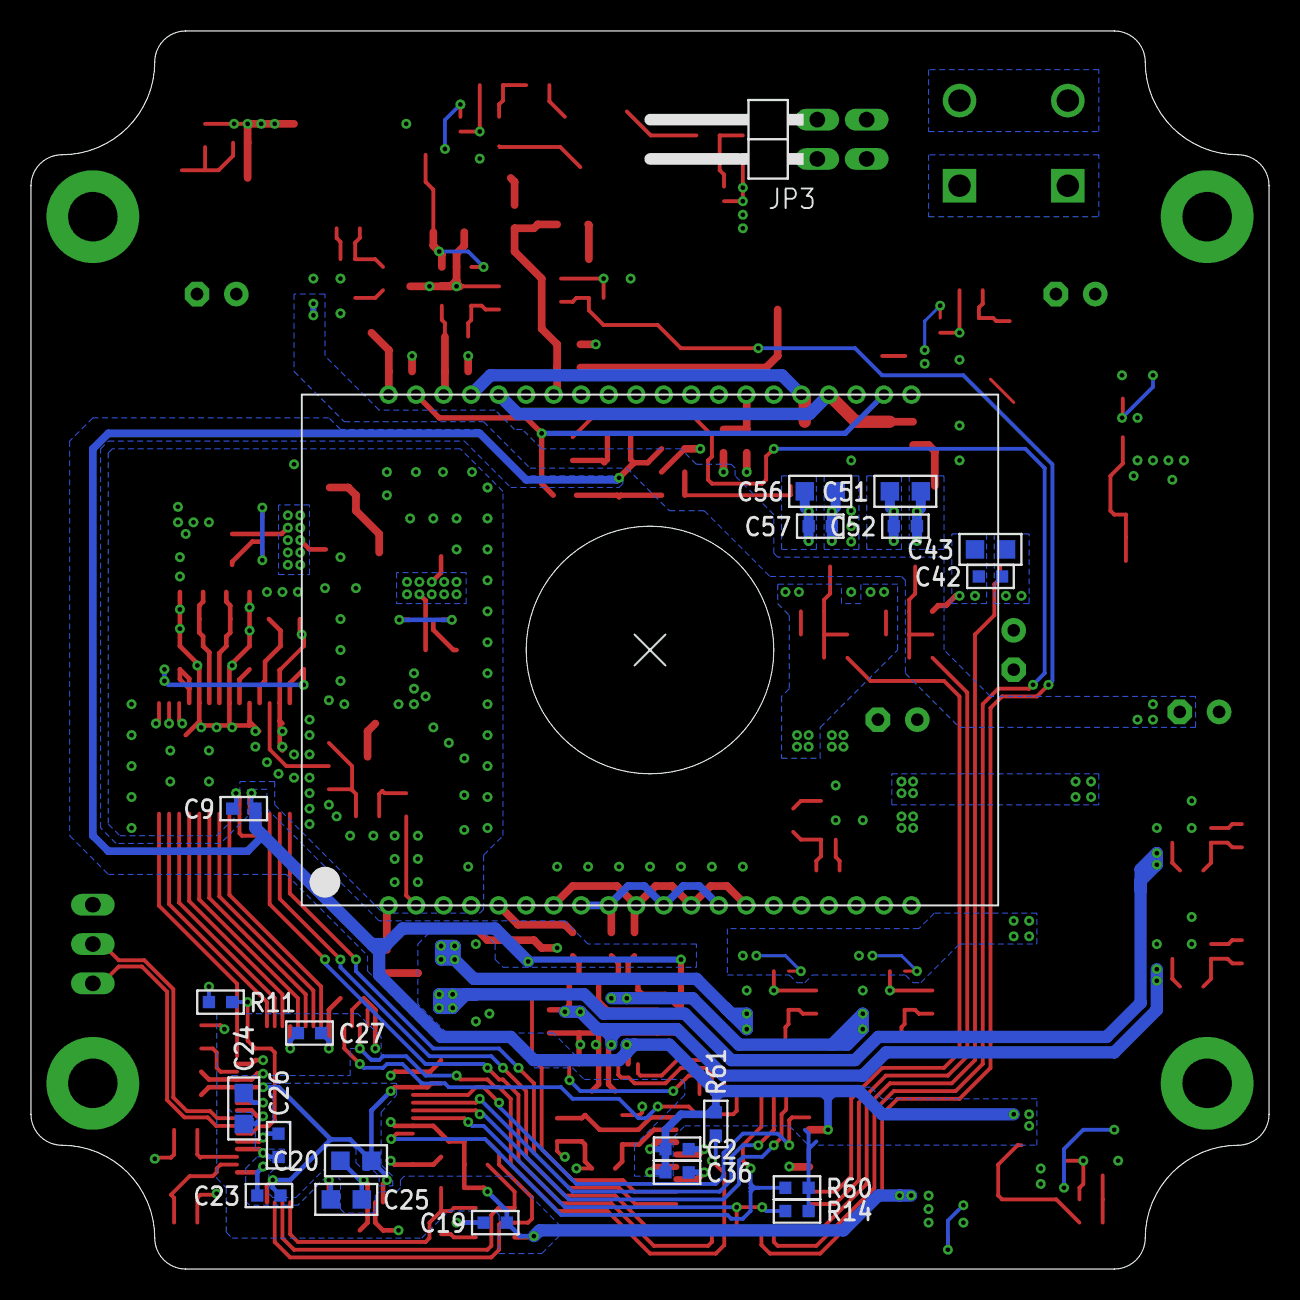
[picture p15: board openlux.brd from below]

Board: 4 copper layers, 80.0 x 80.0 mm, 219 parts (22 on the bottom side), 109 nets.

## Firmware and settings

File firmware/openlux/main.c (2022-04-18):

/*
 * openlux.c
 *
 * Created: 26/06/2021 15:34:56
 * Author : jpe
 */ 

#define F_CPU 20000000L

#include <stdint.h>
#include <avr/io.h>
#include <avr/interrupt.h>
#include <util/delay.h>

#include "main.h"

/*int STATE0 = 0b01100011;
int STATE1 = 0b01111001;
int STATE2 = 0b01110000;
int STATE3 = 0b10110101;
int STATE4 = 0b10110111;
int STATE5 = 0b10110010;*/

#define CLK_V1      0b00000001
#define CLK_V2      0b00000010
#define CLK_V2H     0b00000100
#define CLK_FD      0b00001000
#define CLK_SHUTTER 0b00010000

#define ADC_SCLK  0b00000010
#define ADC_SLOAD 0b00100000
#define ADC_DATA  0b00100000

#define IDLE 0b01110010
#define LDLE 0b01110010

#define REG_CFG   0
#define REG_MUX   1
#define REG_PGA_R 2
#define REG_PGA_G 3
#define REG_PGA_B 4
#define REG_OFF_R 5
#define REG_OFF_G 6
#define REG_OFF_B 7

#define PIXEL PORTD = STATE0; \
              PORTD = STATE1; \
			  PORTD = STATE2; \
			  PORTD = STATE3; \
			  PORTD = STATE3; \
			  PORTD = STATE4; \
			  PORTD = STATE5; \
			  PORTD = STATE6; \
			  PORTD = STATE7; \
			  PORTD = STATE7;
			  
#define PIXEL4 PIXEL \
               PIXEL \
			   PIXEL \
			   PIXEL
			   
#define PIXEL16 PIXEL4 \
                PIXEL4 \
				PIXEL4 \
				PIXEL4
				
#define PIXEL64 PIXEL16 \
                PIXEL16 \
				PIXEL16 \
				PIXEL16
				
#define PIXEL256 PIXEL64 \
                 PIXEL64 \
				 PIXEL64 \
				 PIXEL64
				 
/*#define PIXEL2048 PIXEL256 \
                  PIXEL256 \
				  PIXEL256 \
				  PIXEL256 \
				  PIXEL256 \
				  PIXEL256 \
				  PIXEL256 \
				  PIXEL256*/

int8_t toread = 0;

int16_t seconds = 0;
int16_t millis = 0;

int main() {
	int temp = 0;

	cli();
	
	SPCR = 0b01000000;
	SPSR |= 1;
	
	DDRD |= 0b11111111;
	PORTD = LDLE;//0b01100011;//STATE0;

	DDRB |= 0b00010010;
	//PORTB |= 0b0;
	PORTB &= ~ADC_SCLK;

	DDRC |= 0b00111111;
	PORTC &= ~(CLK_V2 | CLK_V2H | CLK_SHUTTER | CLK_FD);
	PORTC |= CLK_V1;// | CLK_FD;

	//_delay_ms(1);
	
	_delay_ms(10);
	
	// 4v range, vref en, single ch, cds mode, 4v clamp bias, enabled, 0, 16 bits
	//adc_write(REG_CFG, 0b011011000);
	adc_write(REG_CFG, 0b011011100);
	_delay_us(10);
	
	// en red ch
	adc_write(REG_MUX, 0b011000000);
	_delay_us(10);

	//adc_write(REG_PGA_R, 59);
	adc_write(REG_PGA_R, 59);
	_delay_us(10);

	adc_write(REG_OFF_R, 10);
	_delay_us(10);
	
	uint8_t ptmp = PORTC;//0;
		for (uint16_t row = 0; row < 2720 * 4; row++) {
			ptmp |= CLK_V2;
			ptmp &= ~CLK_V1;
			PORTC = ptmp;
			
			_delay_us(15);
			
			ptmp |= CLK_V1;
			ptmp &= ~CLK_V2;
			PORTC = ptmp;
			
			//_delay_us(235);
			_delay_us(15);
		}
	
	_delay_ms(1);
	
	//uint8_t ptmp = PORTC;//0;

    while (1) 
    {
		cli();
		
		//while (SPSR & 0b10000000 == 0);
		while (1 == 1) {
			while(!(SPSR & (1<<SPIF))) {
				ptmp |= CLK_V2;
				ptmp &= ~CLK_V1;
				PORTC = ptmp;
					
				_delay_us(15);
					
				ptmp |= CLK_V1;
				ptmp &= ~CLK_V2;
				PORTC = ptmp;
					
				//_delay_us(985);
				_delay_us(2000);
				//_delay_us(5000); // TODO
			}
		
			temp = SPDR;
			
			if (toread > 0) {
				if (toread == 4) {
					seconds = temp;
					seconds <<= 8;
					toread--;
				} else if (toread == 3) {
					seconds |= temp;
					toread--;
				} else if (toread == 2) {
					millis = temp;
					millis <<= 8;
					toread--;
				} else if (toread == 1) {
					millis |= temp;
					toread--;
					break;
				}
			} else if (temp == 0xaa) {
				toread = 4;
			}
			
			temp = SPSR;
		}
		
		PORTC &= ~CLK_V1;
		_delay_us(15);
		
		PORTC |= CLK_SHUTTER;
		_delay_us(5);
		PORTC &= ~CLK_SHUTTER;
		
		for (uint16_t k = 0; k < seconds; k++) {
			_delay_ms(1000);
		}
		
		if (millis > 999) millis = 999;
		
		for (uint16_t k = 0; k < millis; k++) {
			_delay_ms(1);
		}
		/*for (uint16_t k = 0; k < 10; k++) {
			_delay_ms(1000);
		}*/
		
		readout();
		_delay_ms(1);
		/*PORTC |= 0b00100000;
		_delay_ms(1);
		PORTC &= ~0b00100000;
		_delay_ms(1);*/
    }
}

void adc_write(uint8_t addr, uint16_t val) {
	DDRC |= 0b00100000;
	PORTB &= ~ADC_SCLK;
	PORTD &= ~ADC_SLOAD;
	
	PORTC &= ~ADC_DATA; // r/w bit 0 for writes
	PORTB |= ADC_SCLK;
	PORTB &= ~ADC_SCLK;
	
	for (uint8_t i = 0; i < 3; i++) {
		PORTC = (PORTC & (~ADC_DATA)) | (((addr >> (2 - i)) & 1) << 5);
		PORTB |= ADC_SCLK;
		PORTB &= ~ADC_SCLK;
	}
	/*PORTC = (PORTC & (~ADC_DATA)) | (((addr >> 2) & 1) << 5)
	PORTB |= ADC_SCLK;
	PORTB &= ~ADC_SCLK;
	PORTC = (PORTC & (~ADC_DATA)) | (((addr >> 1) & 1) << 5)
	PORTB |= ADC_SCLK;
	PORTB &= ~ADC_SCLK;
	PORTC = (PORTC & (~ADC_DATA)) | (((addr >> 0) & 1) << 5)
	PORTB |= ADC_SCLK;
	PORTB &= ~ADC_SCLK;*/
	
	PORTC &= ~ADC_DATA;
	for (uint8_t i = 0; i < 3; i++) {
		PORTB |= ADC_SCLK;
		PORTB &= ~ADC_SCLK;
	}
	
	for (uint8_t i = 0; i < 9; i++) {
		PORTC = (PORTC & (~ADC_DATA)) | (((val >> (8 - i)) & 1) << 5);
		PORTB |= ADC_SCLK;
		PORTB &= ~ADC_SCLK;
	}
	
	PORTD |= ADC_SLOAD;
}

uint16_t adc_read(uint8_t addr) {
	uint16_t val = 0;
	
	DDRC |= 0b00100000;
	PORTB &= ~ADC_SCLK;
	PORTD &= ~ADC_SLOAD;
	
	PORTC |= ADC_DATA; // r/w bit 1 for reads
	PORTB |= ADC_SCLK;
	PORTB &= ~ADC_SCLK;
	
	for (uint8_t i = 0; i < 3; i++) {
		PORTC = (PORTC & (~ADC_DATA)) | (((addr >> (2 - i)) & 1) << 5);
		PORTB |= ADC_SCLK;
		PORTB &= ~ADC_SCLK;
	}
	
	PORTC &= ~ADC_DATA;
	DDRC &= ~0b00100000;
	for (uint8_t i = 0; i < 3; i++) {
		PORTB |= ADC_SCLK;
		PORTB &= ~ADC_SCLK;
	}
	
	for (uint8_t i = 0; i < 9; i++) {
		//PORTC = (PORTC & (~ADC_DATA)) | (((val >> (8 - i)) & 1) << 5)
		val |= (PORTC >> 5 & 1) << (8 - i);
		PORTB |= ADC_SCLK;
		PORTB &= ~ADC_SCLK;
	}
	
	PORTD |= ADC_SLOAD;
	DDRC |= 0b00100000;
	
	return val;
}

void readout() {
	int STATE0 = 0b01100010;
	int STATE1 = 0b01110011;
	int STATE2 = 0b01111001;
	int STATE3 = 0b01110000;
	int STATE4 = 0b10110000;
	int STATE5 = 0b10110101;
	int STATE6 = 0b10110111;
	int STATE7 = 0b10110010;
	/*int STATE0 = 0b01100011;
	int STATE1 = 0b01111000;
	int STATE2 = 0b01110001;
	int STATE3 = 0b10110101;
	int STATE4 = 0b10110110;
	int STATE5 = 0b10110011;*/
	
	//PORTD = IDLE;//STATE0;
	
	uint8_t temp = PORTC;
	temp |= CLK_V1;
	PORTC = temp;
	_delay_us(15);
	
	for (uint16_t row = 0; row < 2720 * 4; row++) {
		temp |= CLK_V2;
		temp &= ~CLK_V1;
		PORTC = temp;
		
		_delay_us(15);
		
		temp |= CLK_V1;
		temp &= ~CLK_V2;
		PORTC = temp;
		
		//_delay_us(235);
		_delay_us(15);
	}
	
	PORTC |= CLK_FD;
	
	PORTC |= CLK_V2;
	
	_delay_us(140);
	
	//uint8_t temp = PORTC;
	temp = PORTC;
	temp |= CLK_V2H;
	temp &= ~CLK_V1;
	//PORTC |= CLK_V2H; // TODO V1
	PORTC = temp;
	
	_delay_us(15);
	
	temp &= ~CLK_V2H;
	temp |= CLK_V1;
	PORTC = temp;

	_delay_us(30);
	
	PORTC &= ~CLK_V2;
	
	PORTD = IDLE; // TODO
	
	adc_write(REG_CFG, 0b011011000);
	
	_delay_us(4);

	for (uint16_t row = 0; row < 2720; row++) {
		// TODO row
		for (uint8_t i = 0; i < 16; i++) {
			PIXEL256;
			PORTD = IDLE;
		}
		
		/*for (uint16_t i = 0; i < 256; i++) {
			PORTD = 0b01100011;
			PORTD = 0b01100010;
		}*/
		
		PORTD = IDLE;//STATE0;
		//PIXEL2048;
		//PIXEL2048;
		
		_delay_us(1);
		
		temp |= CLK_V2;
		temp &= ~CLK_V1;
		PORTC = temp;
		
		_delay_us(15);
		
		temp |= CLK_V1;
		temp &= ~CLK_V2;
		PORTC = temp;
		
		_delay_us(12);
	}
	
	PORTD = LDLE;
	
	adc_write(REG_CFG, 0b011011100);
	
	PORTC &= ~CLK_FD;
}
